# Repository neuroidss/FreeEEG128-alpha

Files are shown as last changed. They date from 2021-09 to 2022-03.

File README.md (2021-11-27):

# FreeEEG128-alpha

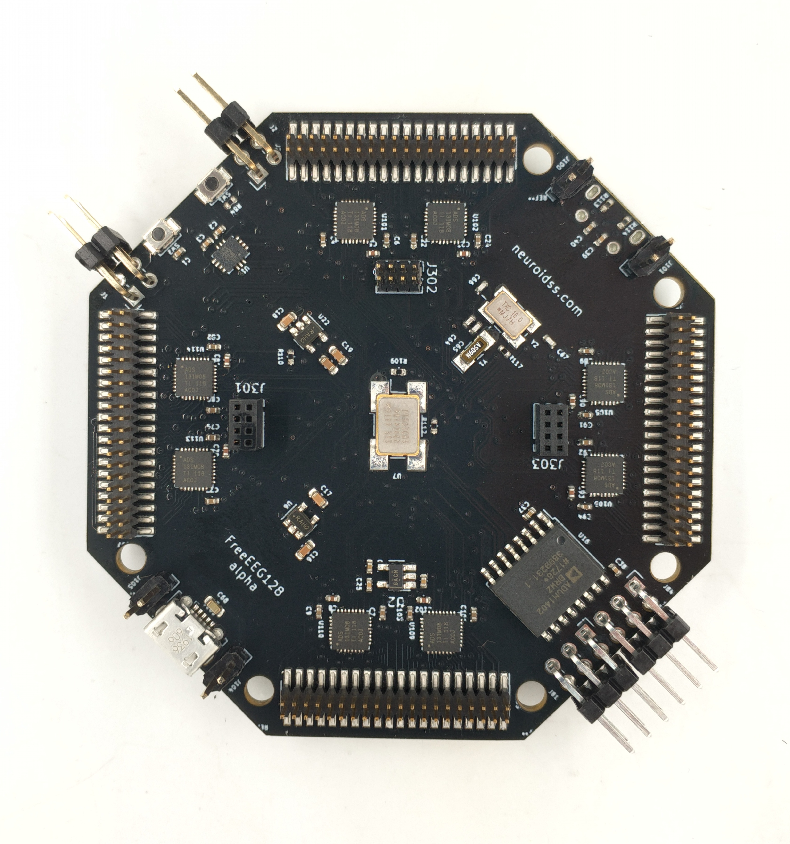
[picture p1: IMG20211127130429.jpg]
FreeEEG128-alpha_top


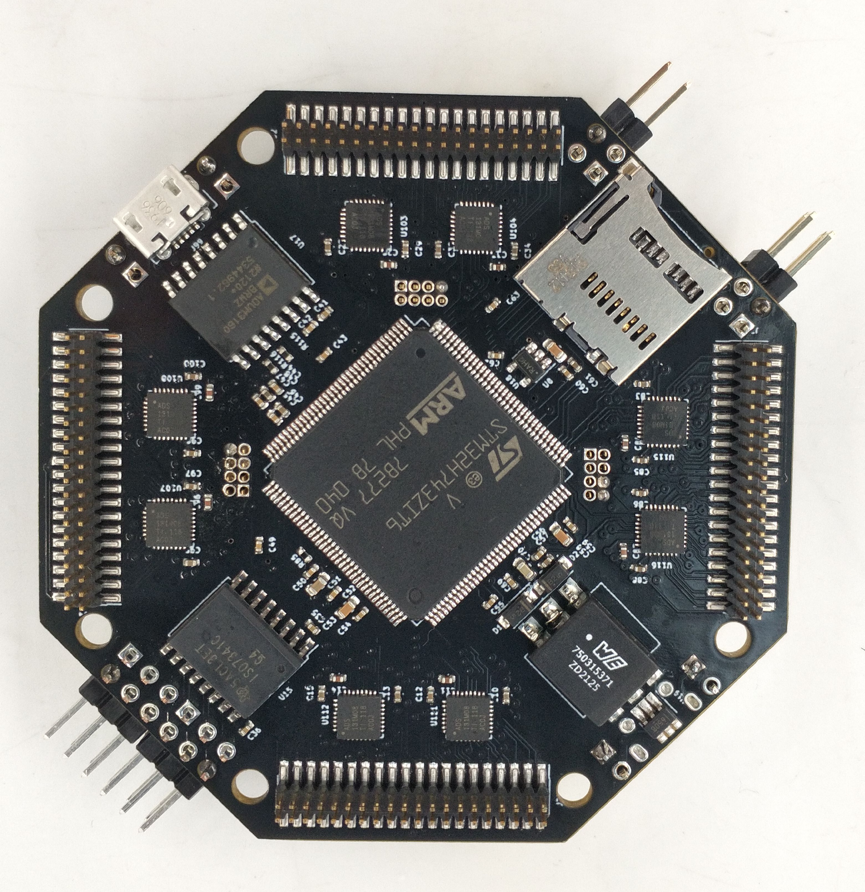
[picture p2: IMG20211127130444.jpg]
FreeEEG128-alpha_bottom


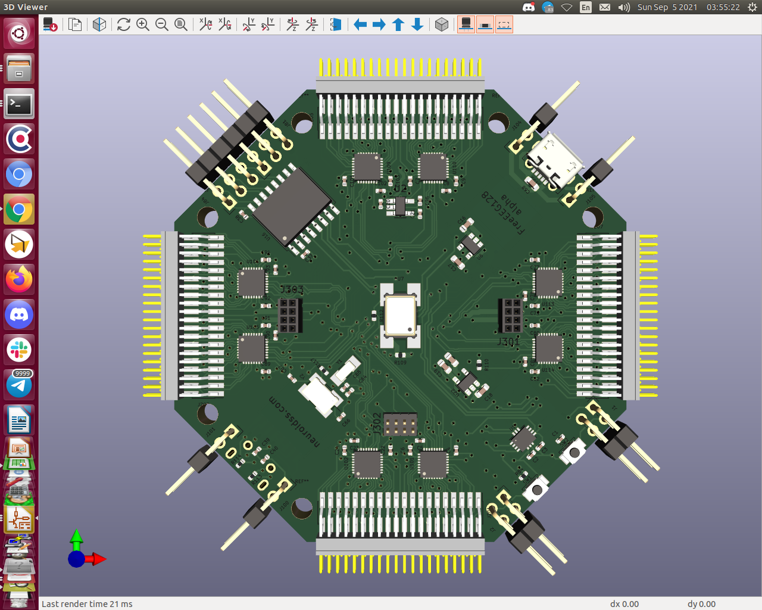
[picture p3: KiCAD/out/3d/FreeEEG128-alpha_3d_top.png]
FreeEEG128-alpha_3d_top


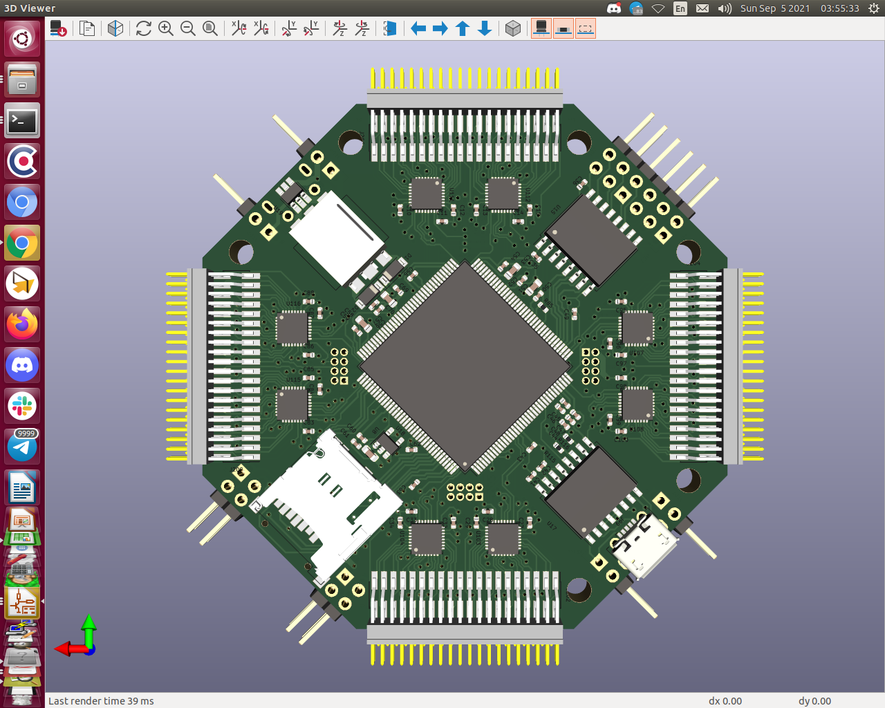
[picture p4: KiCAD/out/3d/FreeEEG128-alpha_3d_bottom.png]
FreeEEG128-alpha_3d_bottom


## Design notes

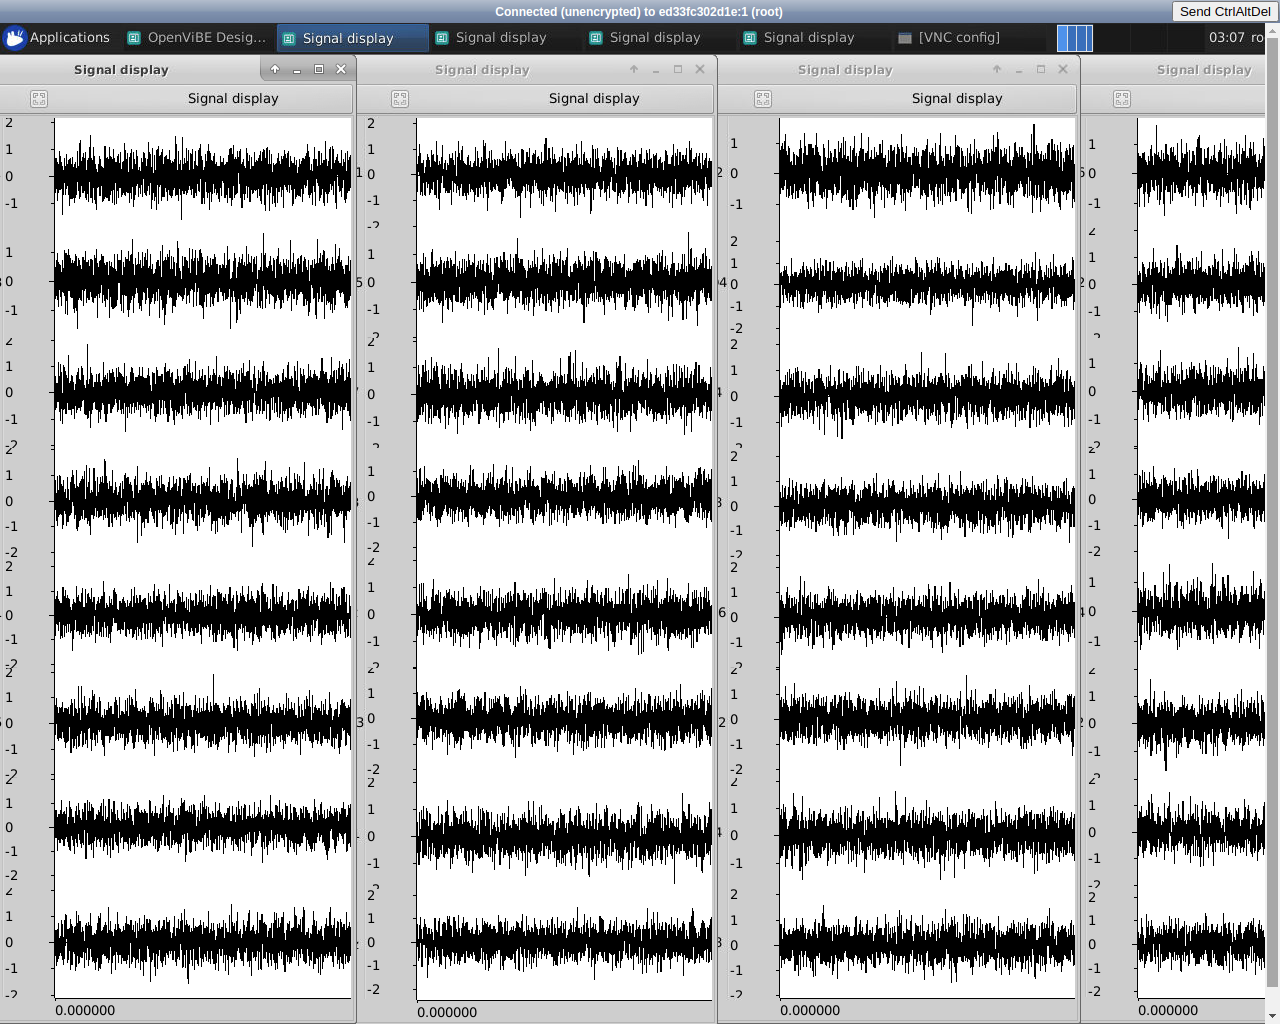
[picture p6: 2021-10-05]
Screenshot from 2021-10-05 06-07-12.png

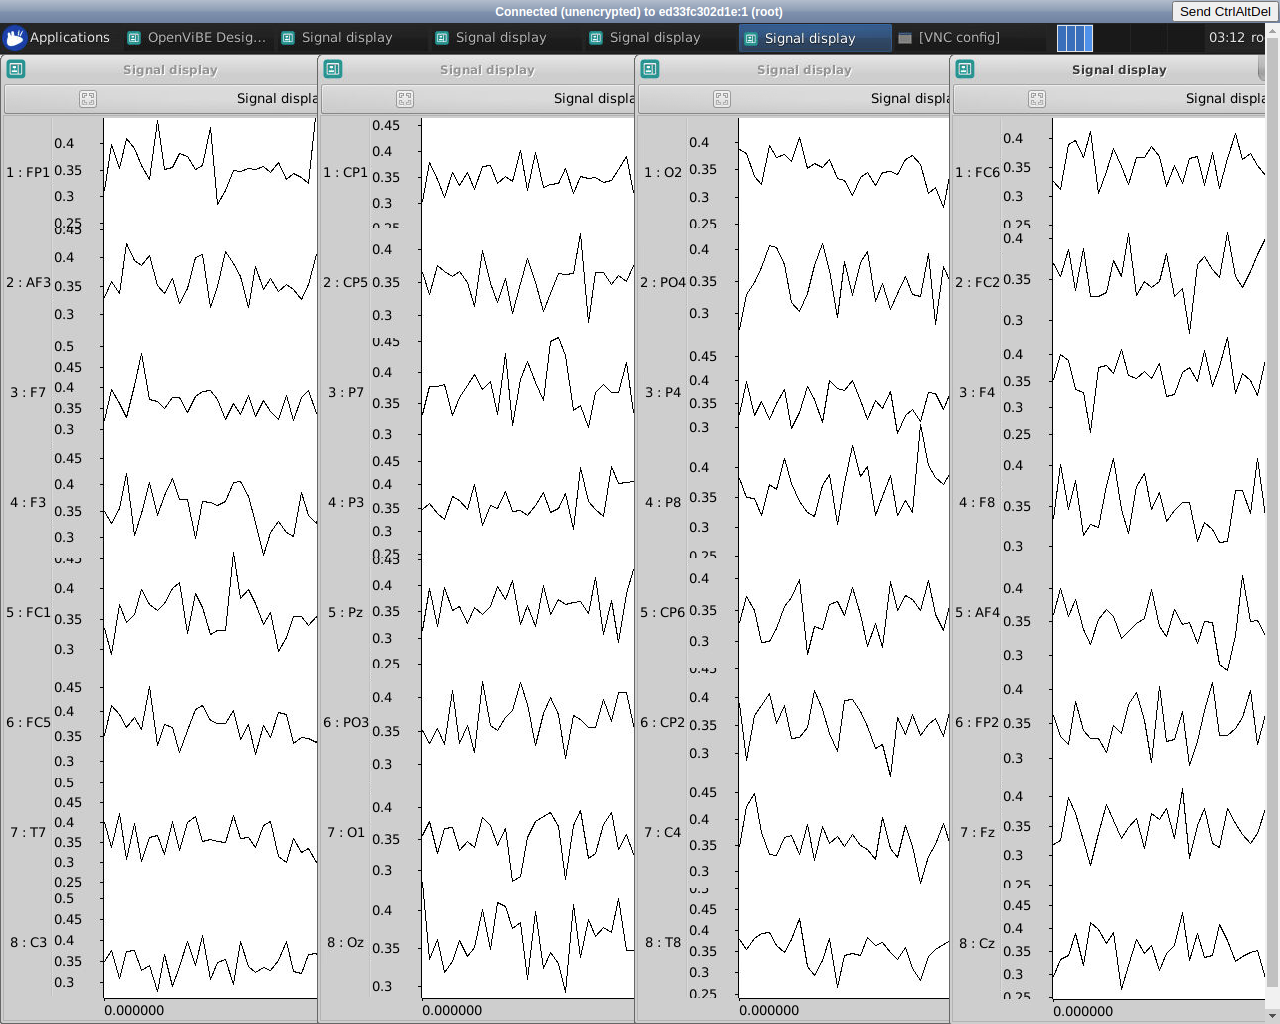
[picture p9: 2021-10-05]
Screenshot from 2021-10-05 06-12-14.png

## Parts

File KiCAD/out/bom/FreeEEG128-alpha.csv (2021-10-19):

Id | Designator | Package | Quantity | Designation | Supplier and ref | Manufacturer Part Number or Seeed SKU | Description | alt
1 | J303,J301 | PinSocket_2x04_P1.27mm_Vertical | 2 | Conn_02x04_Odd_Even |  | 20021311-00008T4LF | CONN RCPT 8POS 0.05 GOLD PCB | 20021311-00008T1LF | LPPB042CFFN-RC
2 | U1 | Bosch_LGA-14_3x2.5mm_P0.5mm | 1 | LSM6DS3 |  | LSM6DSOXTR | IMU ACCEL/GYRO I2C/SPI 14TFLGA | LSM6DS3TR | LSM6DSRXTR | LSM6DSOXTR
3 | C38,C39,C1,C40,C2,C3,C37,C25,C21,C20,C47,C50,C59,C43,C55,C42,C35,C63,C54,C62,C69,C56,C49,C44,C45,C36,C41,C60,C52 | C_0402_1005Metric | 29 | 100n |  | CL05B104KO5NNNC | CAP CER 0.1UF 16V X7R 0402
4 | C66,C64 | C_0402_1005Metric | 2 | CL1 |  | GRM1555C1H200JA01D | CAP CER 20PF 50V C0G/NP0 0402
5 | C16,C17,C19,C18,C76,C53,C58,C75 | C_0603_1608Metric | 8 | 2.2u |  | GRM188R71A225KE15D | CAP CER 2.2UF 10V 10% X7R 0603
6 | R84,R85 | R_0402_1005Metric | 2 | 4k7 |  | RC0402JR-074K7L | RES 4.7K OHM 1/16W 5% 0402 SMD
7 | R113,R114,R116,R115 | R_0402_1005Metric | 4 | 24 |  | RC0402FR-0724RL | RES SMD 24 OHM 1% 1/16W 0402
8 | J104,J105,J100,J101 | PinHeader_2x01_P2.54mm_Horizontal | 4 | Conn_01x02 |  | PRPC001DAAN-RC | CONN HEADER VERT 2POS | PRPC001DAAN-RC | TSW-101-07-F-D
9 | U6,U22,U8 | SOT-23-5 | 3 | LP5907 |  | LP5907QMFX-3.3Q1 | IC REG LINEAR 3.3V 250MA SOT23-5 | ADP7118AUJZ-3.3-R7
10 | Y2 | Crystal_SMD_EuroQuartz_MJ-4Pin_5.0x3.2mm_HandSoldering | 1 | 16MHz |  | 7B-16.000MEEQ-T | CRYSTAL 16.0000MHZ 10PF SMD
11 | C67,C65 | C_0402_1005Metric | 2 | CL2 |  | GRM1555C1H200JA01D | CAP CER 20PF 50V C0G/NP0 0402
12 | C68,C70 | C_0603_1608Metric | 2 | 10u |  | GRM188R60J106ME47D | CAP CER 10UF 6.3V 20% X5R 0603
13 | J103,J99 | USB_Micro-B_Molex-105017-0001 | 2 | USB_B_Micro |  | 105017-1001 | CONN RCPT USB2.0 MICRO B SMD R/A
14 | SW1,SW2 | SW_SPST_B3U-1000P-B | 2 | SW_Push |  | B3U-1000P | Switch Tactile N.O. SPST Round Button Gull Wing 0.05A 12VDC 1.5N SMD Embossed T/R
15 | Y1 | Crystal_SMD_EuroQuartz_EQ161-2Pin_3.2x1.5mm_HandSoldering | 1 | 32768Hz |  | FC-135 32.7680KA-A5 | CRYSTAL 32.7680 KHZ 12.5PF SMD
16 | U7 | Oscillator_SMD_EuroQuartz_XO91-4Pin_7.0x5.0mm_HandSoldering | 1 | FXO-SM7_OSC-SMD7050_short |  | CB3LV-3I-8M1920 | XTAL OSC XO 8.1920MHZ HCMOS TTL
17 | R117 | R_0402_1005Metric | 1 | R_EXT |  | RC0402JR-070RL | RES 0.0 OHM 1/16W JUMP 0402 SMD
18 | J2,J1 | PinHeader_2x02_P2.54mm_Horizontal | 2 | Conn_02x02_Odd_Even |  | 68021-404HLF | CONN HEADER R/A 4POS 2.54MM | PREC002DBAN-M71RC | M20-9950245 | TSW-102-08-T-D-RA | HTSW-102-08-T-D-RA | 68021-404HLF
19 | U16 | SOIC-16W_7.5x10.3mm_P1.27mm | 1 | ADUM1402BRWZ |  | ADUM1402BRWZ | digital isolator 10Mbps 2.7÷5.5VDC SMD SO16-W | ADUM142E1BRWZ
20 | J81,J84 | PinHeader_2x03_P2.54mm_Horizontal | 2 | Conn_02x03_Odd_Even |  | 68021-406HLF | CONN HEADER R/A 6POS 2.54MM | PREC003DBAN-M71RC | PH2RA-06-UA | TSW-103-08-T-D-RA |  | 68021-406HLF
21 | C81,C5,C90,C8,C102,C78,C93,C23,C84,C28,C11,C99,C33,C87,C14,C96 | C_0402_1005Metric | 16 | 220nF |  | CC0402KRX5R5BB224 | CAP CER 0.22UF 16V X7R 0402
22 | C79,C82,C91,C92,C94,C101,C22,C6,C9,C103,C89,C24,C4,C77,C7,C80,C61,C46,C57,C48,C95,C83,C15,C12,C97,C85,C13,C88,C32,C29,C27,C10,C98,C86,C100,C34 | C_0402_1005Metric | 36 | 1u |  | CL05A105KO5NNNC | CAP CER 1UF 16V X5R 0402
23 | U113,U109,U114,U105,U102,U106,U110,U101,U103,U107,U112,U116,U108,U111,U104,U115 | QFN-32-1EP_4x4mm_P0.4mm_EP2.65x2.65mm_ThermalVias | 16 | ADS131M08IRSN |  | ADS131M08IRSN | IC ADC 24BIT SIGMA-DELTA 32WQFN
24 | J207,J203,J201,J205,J208,J204,J202,J206 | PinHeader_2x20_P1.27mm_Vertical_SMD | 8 | Conn_02x20_Odd_Even |  | 20021121-00040T4LF | CONN HEADER SMD 40POS 1.27MM | M50-3612042R | FTSH-120-01-F-DV | M50-3602042 | M50-3612042 |  | FTSH-120-01-F-DV-P | FTSH-120-01-F-DH-A | FTSH-120-04-F-DH-A
25 | J302 | PinHeader_2x04_P1.27mm_Vertical | 1 | Conn_02x04_Odd_Even |  | HPH2-A-08-UA | CONN HEADER VERT 8POS 1.27MM | GRPB042VWVN-RC | 20021111-00008T4LF
27 | R112,R110,R109 | R_0402_1005Metric | 3 | 0 |  | RC0402JR-070RL | RES 0.0 OHM 1/16W JUMP 0402 SMD
28 | U2 | SOT-23-5_HandSoldering | 1 | REF2025 |  | REF2025AIDDC | IC VREF SERIES 1.25V 2.5V SOT-23-5
29 | U19 | SOT-23-6_Handsoldering | 1 | SN6505B |  | SN6505BDBVR | IC TRANSFORMER DRIVER 6SOT-23
30 | C51 | C_0603_1608Metric | 1 | 4.7u |  | C0603C475K9PACTU | CAP CER 4.7UF 6.3V 10% X5R 0603
31 | U18 | LQFP-144_20x20mm_P0.5mm | 1 | STM32H743ZITx |  | STM32H743ZIT6U | HIGH-PERFORMANCE AND DSP WITH DP
32 | U17 | SOIC-16W_7.5x10.3mm_P1.27mm | 1 | ADuM3160 |  | ADUM3160BRWZ | Digital Isolator CMOS 2-CH 12Mbps 16-Pin SOIC W Tube
33 | D2,D1 | D_SOD-123 | 2 | D_Schottky |  | MBR0520LT1G | Rectifier, Schottky Power; Plastic Sod-123; 0.5 a @ +90c If; +125; 20v; 1000
34 | U15 | SOIC-16W_7.5x10.3mm_P1.27mm | 1 | ISO7341c |  | ISO7341CDW | DGTL ISO 3KV 4CH GEN PURP 16SOIC
35 | U21 | 473521001 | 1 | 473521001 |  | 47352-1001 | CONN MICRO SD CARD PUSH-PUSH R/A
36 | T1 | 750315371 | 1 | 750315371 |  | 750315371 | XFRMR FWD P-P DC/DC CONV SMD

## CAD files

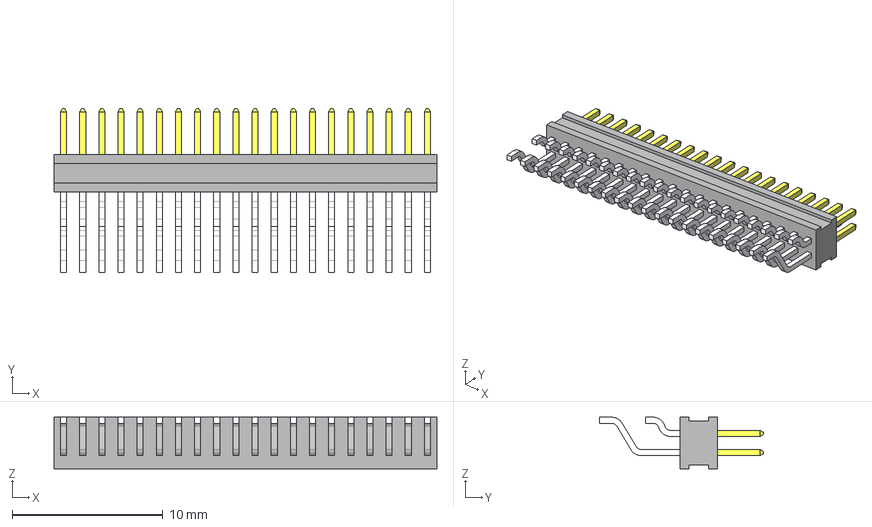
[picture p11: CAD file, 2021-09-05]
KiCAD/3d/Connectors/FTSH-120-01-L-DH-TR.stp
25.4 x 10.9 x 3.43 mm
_FTSH-120-01-L-DH-TR_body
_FTSH-120-01-L-DH-TR_pins1
_FTSH-120-01-L-DH-TR_pins2

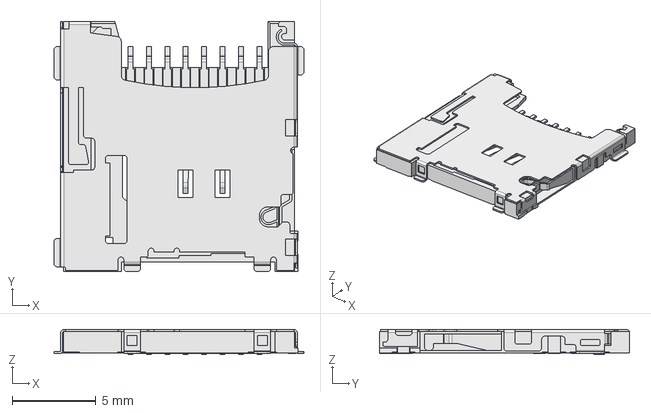
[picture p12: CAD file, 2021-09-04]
KiCAD/3d/Connectors/5031821852.step
14.9 x 14.9 x 1.50 mm

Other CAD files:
KiCAD/3d/Connectors/5031821852.stp

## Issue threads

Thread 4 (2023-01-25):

on freeeeg128-alpha no vref for boards interconnection

dmitry-sukhoruchkin, 2023-01-25:
on freeeeg128-alpha no vref for boards interconnection, vref gnd instead, which duplicated already existed gnd on another connector

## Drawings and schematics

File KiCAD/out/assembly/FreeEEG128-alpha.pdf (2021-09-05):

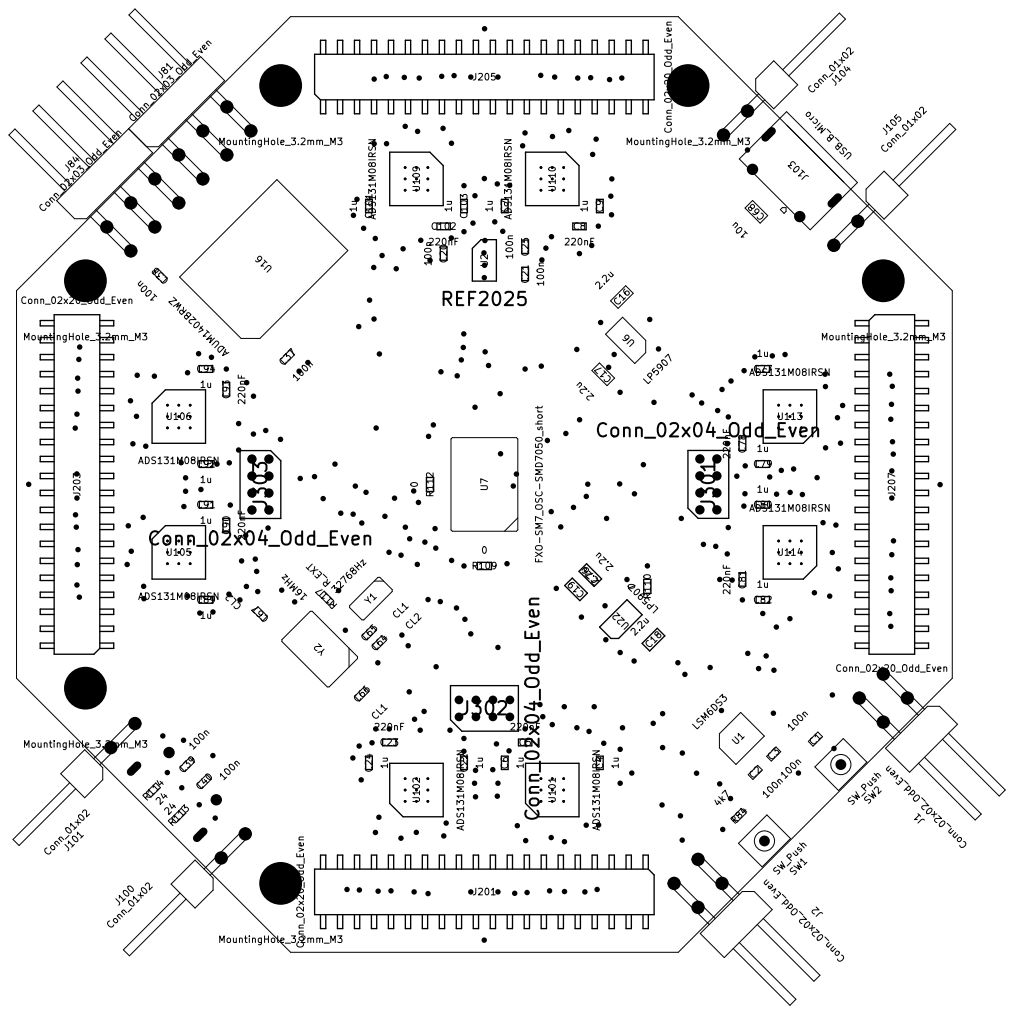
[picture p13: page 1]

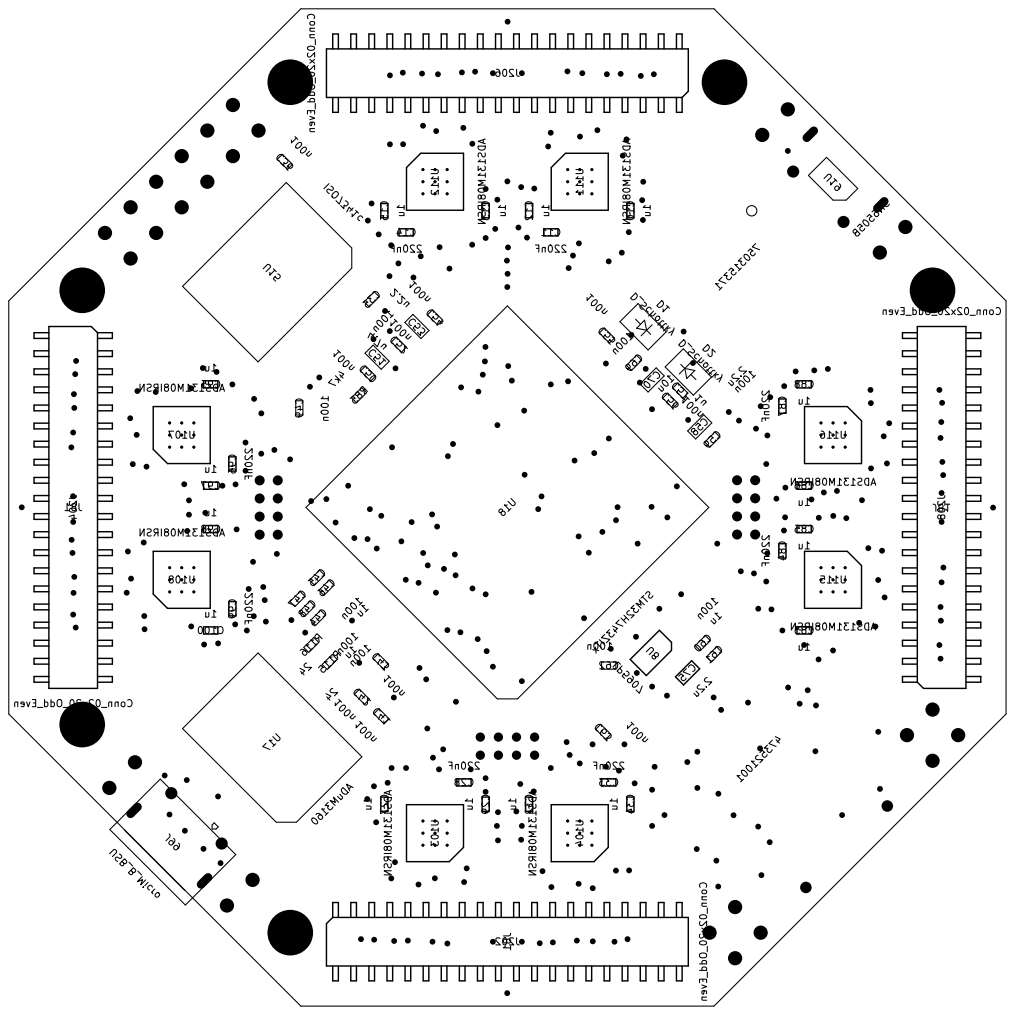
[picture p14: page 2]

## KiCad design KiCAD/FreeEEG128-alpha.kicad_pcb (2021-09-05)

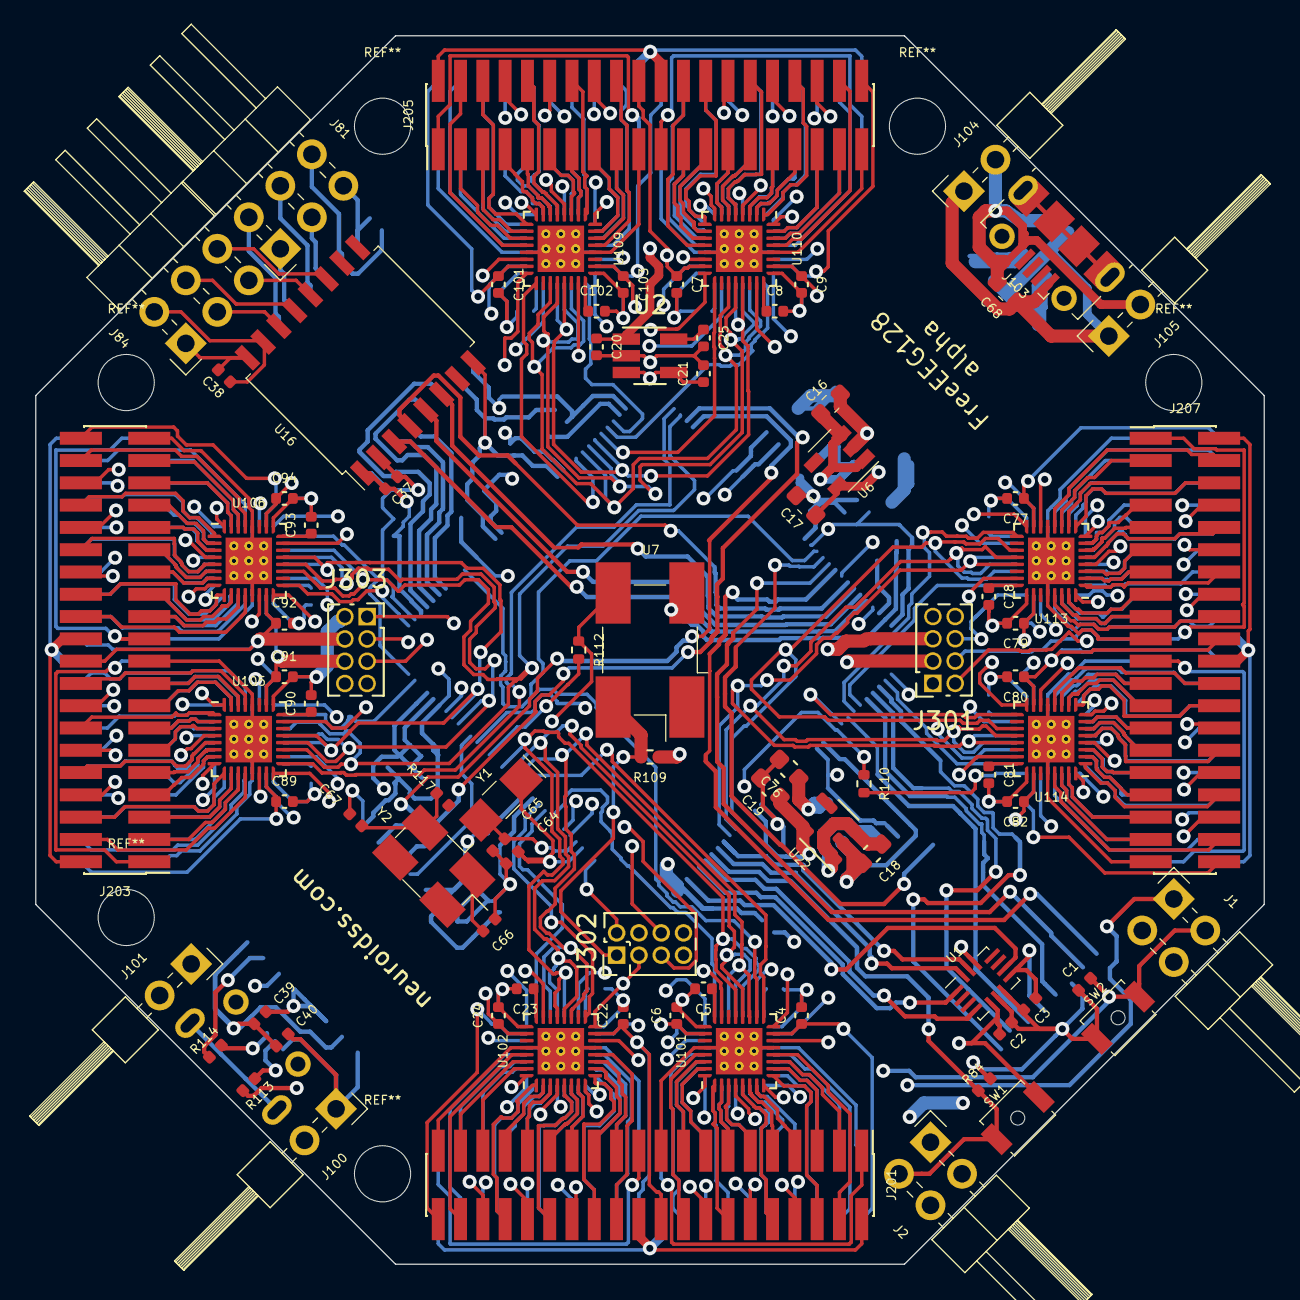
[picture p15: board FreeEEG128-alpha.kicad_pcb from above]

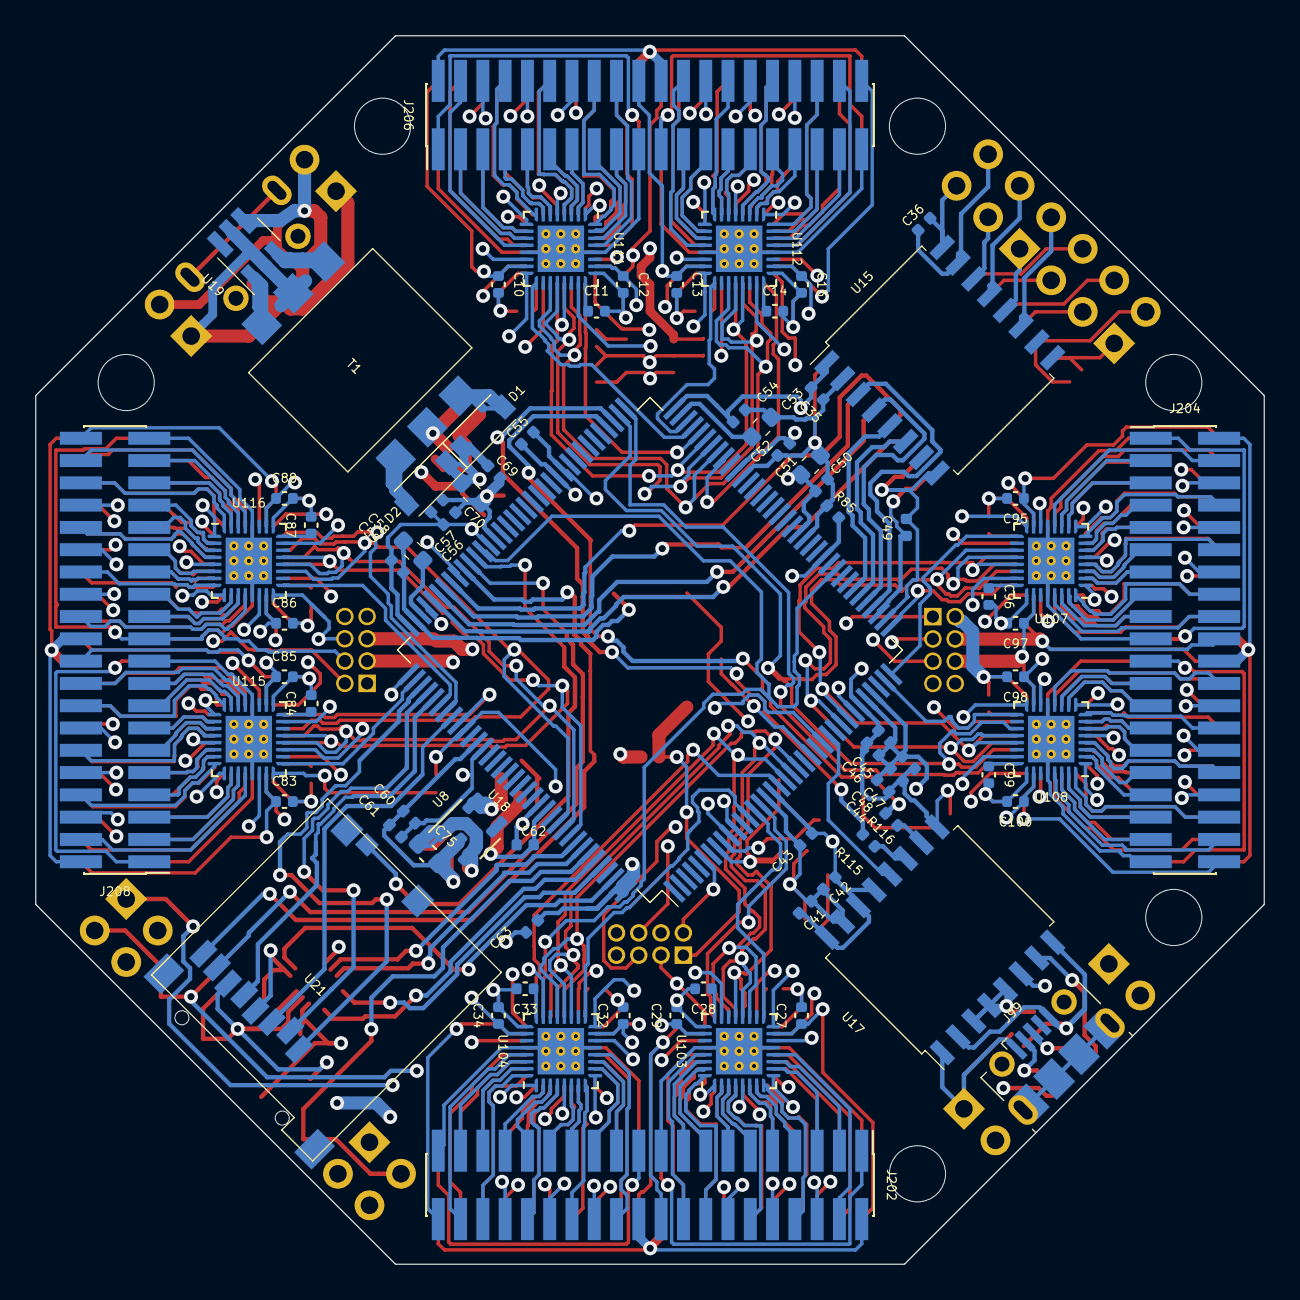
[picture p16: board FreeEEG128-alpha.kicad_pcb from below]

Board: 4 copper layers, 70.0 x 70.0 mm, 162 parts (77 on the bottom side), 379 nets.

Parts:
C1, C2, C3, C20, C21, C25, C35, C36, C37, C38, C39, C40, C41, C42, C43, C44, C45, C47, C49, C50, C52, C54, C55, C56, C59, C60, C62, C63, C69: 100n; C_0402_1005Metric
C4, C6, C7, C9, C10, C12, C13, C15, C22, C24, C27, C29, C32, C34, C46, C48, C57, C61, C77, C79, C80, C82, C83, C85, C86, C88, C89, C91, C92, C94, C95, C97, C98, C100, C101, C103: 1u; C_0402_1005Metric
C5, C8, C11, C14, C23, C28, C33, C78, C81, C84, C87, C90, C93, C96, C99, C102: 220nF; C_0402_1005Metric
C16, C17, C18, C19, C53, C58, C75, C76: 2.2u; C_0603_1608Metric
C51: 4.7u; C_0603_1608Metric
C64, C66: CL1; C_0402_1005Metric
C65, C67: CL2; C_0402_1005Metric
C68, C70: 10u; C_0603_1608Metric
D1, D2: D_Schottky; D_SOD-123
J1, J2: Conn_02x02_Odd_Even; PinHeader_2x02_P2.54mm_Horizontal
J81, J84: Conn_02x03_Odd_Even; PinHeader_2x03_P2.54mm_Horizontal
J99, J103: USB_B_Micro; USB_Micro-B_Molex-105017-0001
J100, J101, J104, J105: Conn_01x02; PinHeader_2x01_P2.54mm_Horizontal
J201, J202, J203, J204, J205, J206, J207, J208: Conn_02x20_Odd_Even; PinHeader_2x20_P1.27mm_Vertical_SMD
J301, J303: Conn_02x04_Odd_Even; PinSocket_2x04_P1.27mm_Vertical
J302: Conn_02x04_Odd_Even; PinHeader_2x04_P1.27mm_Vertical
R84, R85: 4k7; R_0402_1005Metric
R109, R110, R112: 0; R_0402_1005Metric
R113, R114, R115, R116: 24; R_0402_1005Metric
R117: R_EXT; R_0402_1005Metric
SW1, SW2: SW_Push; SW_SPST_B3U-1000P-B
T1: 750315371
U1: LSM6DS3; Bosch_LGA-14_3x2.5mm_P0.5mm
U2: REF2025; SOT-23-5_HandSoldering
U6, U8, U22: LP5907; SOT-23-5
U7: FXO-SM7_OSC-SMD7050_short; Oscillator_SMD_EuroQuartz_XO91-4Pin_7.0x5.0mm_HandSoldering
U15: ISO7341c; SOIC-16W_7.5x10.3mm_P1.27mm
U16: ADUM1402BRWZ; SOIC-16W_7.5x10.3mm_P1.27mm
U17: ADuM3160; SOIC-16W_7.5x10.3mm_P1.27mm
U18: STM32H743ZITx; LQFP-144_20x20mm_P0.5mm
U19: SN6505B; SOT-23-6_Handsoldering
U21: 473521001
U101, U102, U103, U104, U105, U106, U107, U108, U109, U110, U111, U112, U113, U114, U115, U116: ADS131M08IRSN; QFN-32-1EP_4x4mm_P0.4mm_EP2.65x2.65mm_ThermalVias
Y1: 32768Hz; Crystal_SMD_EuroQuartz_EQ161-2Pin_3.2x1.5mm_HandSoldering
Y2: 16MHz; Crystal_SMD_EuroQuartz_MJ-4Pin_5.0x3.2mm_HandSoldering

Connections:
/ADC1/24_CAP: C5.1, U101.24 (CAP)
/ADC2/24_CAP: C23.1, U102.24 (CAP)
/ADC3/24_CAP: C28.1, U103.24 (CAP)
/ADC4/24_CAP: C33.1, U104.24 (CAP)
/ADC5/24_CAP: C90.1, U105.24 (CAP)
/ADC6/24_CAP: C93.1, U106.24 (CAP)
/ADC7/24_CAP: C96.1, U107.24 (CAP)
/ADC8/24_CAP: C99.1, U108.24 (CAP)
/ADC9/24_CAP: C102.1, U109.24 (CAP)
/ADC10/24_CAP: C8.1, U110.24 (CAP)
/ADC11/24_CAP: C11.1, U111.24 (CAP)
/ADC12/24_CAP: C14.1, U112.24 (CAP)
/ADC13/24_CAP: C78.1, U113.24 (CAP)
/ADC14/24_CAP: C81.1, U114.24 (CAP)
/ADC15/24_CAP: C84.1, U115.24 (CAP)
/ADC16/24_CAP: C87.1, U116.24 (CAP)
/MCU/8_PC14: C64.1, U18.8 (PC14), Y1.1
/MCU/9_PC15: C65.1, U18.9 (PC15), Y1.2
/MCU/71_VCAP_1: C53.1, U18.71 (VCAP1)
/MCU/106_VCAP_2: C58.1, U18.106 (VCAP2)
ACC_1_SDO_SAO: U1.1 (SDO/SA0), U18.140 (PB9)
ACC_4_INT1: U1.4 (INT1), U18.139 (PB8)
ACC_6_GND: C1.1, C2.2, C3.2, C4.2, C5.2, C6.2, C7.2, C8.2, C9.2, C10.2, C11.2, C12.2, C13.2, C14.2, C15.2, C16.2, C17.2, C18.2, C19.2, C20.2, C21.2, C22.2, C23.2, C24.2, C25.2, C27.2, C28.2, C29.2, C32.2, C33.2, C34.2, C35.2, C37.2, C41.2, C42.2, C43.2, C44.2, C45.2, C46.2, C47.2, C48.2, C49.2, C50.2, C51.2, C52.2, C53.2, C54.2, C55.2, C56.2, C57.2, C58.2, C59.2, C60.2, C61.2, C62.2, C63.2, C64.2, C65.2, C66.2, C67.2, C69.2, C70.2, C75.2, C76.2, C77.2, C78.2, C79.2, C80.2, C81.2, C82.2, C83.2, C84.2, C85.2, C86.2, C87.2, C88.2, C89.2, C90.2, C91.2, C92.2, C93.2, C94.2, C95.2, C96.2, C97.2, C98.2, C99.2, C100.2, C101.2, C102.2, C103.2, J2.2, J201.19, J201.39, J202.19, J202.39, J203.19, J203.39, J204.19, J204.39, J205.19, J205.39, J206.19, J206.39, J207.19, J207.39, J208.19, J208.39, J301.1, J303.2, R84.2, R85.2, SW2.1, T1.5, U1.6 (GND), U1.7 (GND), U2.2 (GND), U6.2 (GND), U7.2 (GND), U8.2 (GND), U15.2 (GND1), U15.8 (GND1), U16.2 (GND1), U16.8 (GND1), U17.9 (GND2), U17.15 (GND2), U18.16 (VSS), U18.31 (VSSA), U18.38 (VSS), U18.51 (VSS), U18.61 (VSS), U18.83 (VSS), U18.94 (VSS), U18.107 (VSS), U18.120 (VSS), U18.130 (VSS), U21.6 (Vss), U22.2 (GND), U101.13 (AGND), U101.25 (DGND), U101.28 (AGND), U101.33 (Thermal_pad), U102.13 (AGND), U102.25 (DGND), U102.28 (AGND), U102.33 (Thermal_pad), U103.13 (AGND), U103.25 (DGND), U103.28 (AGND), U103.33 (Thermal_pad), U104.13 (AGND), U104.25 (DGND), U104.28 (AGND), U104.33 (Thermal_pad), U105.13 (AGND), U105.25 (DGND), U105.28 (AGND), U105.33 (Thermal_pad), U106.13 (AGND), U106.25 (DGND), U106.28 (AGND), U106.33 (Thermal_pad), U107.13 (AGND), U107.25 (DGND), U107.28 (AGND), U107.33 (Thermal_pad), U108.13 (AGND), U108.25 (DGND), U108.28 (AGND), U108.33 (Thermal_pad), U109.13 (AGND), U109.25 (DGND), U109.28 (AGND), U109.33 (Thermal_pad), U110.13 (AGND), U110.25 (DGND), U110.28 (AGND), U110.33 (Thermal_pad), U111.13 (AGND), U111.25 (DGND), U111.28 (AGND), U111.33 (Thermal_pad), U112.13 (AGND), U112.25 (DGND), U112.28 (AGND), U112.33 (Thermal_pad), U113.13 (AGND), U113.25 (DGND), U113.28 (AGND), U113.33 (Thermal_pad), U114.13 (AGND), U114.25 (DGND), U114.28 (AGND), U114.33 (Thermal_pad), U115.13 (AGND), U115.25 (DGND), U115.28 (AGND), U115.33 (Thermal_pad), U116.13 (AGND), U116.25 (DGND), U116.28 (AGND), U116.33 (Thermal_pad)
ACC_9_INT2: U1.9 (INT2), U18.142 (PE1)
ACC_12_CS: C2.1, C3.1, C19.1, C35.1, C37.1, C41.1, C42.1, C43.1, C44.1, C45.1, C46.1, C47.1, C48.1, C49.1, C50.1, C51.1, C52.1, C54.1, C55.1, C56.1, C57.1, C59.1, C60.1, C61.1, C62.1, C63.1, J2.1, J301.5, J302.2, R109.1, SW1.1, U1.5 (VDDIO), U1.8 (VDD), U1.12 (CS), U15.1 (VCC1), U16.1 (VCC1), U17.13 (SPD), U17.14 (VDD2), U17.16 (VBUS2), U18.6 (VBAT), U18.17 (VDD), U18.30 (VDD), U18.32 (VREF+), U18.33 (VDDA), U18.39 (VDD), U18.52 (VDD), U18.62 (VDD), U18.72 (VDD), U18.84 (VDD), U18.95 (VDD33_USB), U18.108 (VDD), U18.121 (VDD), U18.131 (VDD), U18.143 (PDR_ON), U18.144 (VDD), U21.4 (VDD), U22.5 (OUT)
ACC_13_SCL: U1.13 (SCL), U18.136 (PB6)
ACC_14_SDA: U1.14 (SDA), U18.137 (PB7)
ADC1_01_AIN2P: J201.14, U101.1 (AIN2P)
ADC1_02_AIN2N: J201.13, U101.2 (AIN2N)
ADC1_03_AIN3N: J201.11, U101.3 (AIN3N)
ADC1_04_AIN3P: J201.12, U101.4 (AIN3P)
ADC1_05_AIN4P: J201.10, U101.5 (AIN4P)
ADC1_06_AIN4N: J201.9, U101.6 (AIN4N)
ADC1_07_AIN5N: J201.7, U101.7 (AIN5N)
ADC1_08_AIN5P: J201.8, U101.8 (AIN5P)
ADC1_09_AIN6P: J201.6, U101.9 (AIN6P)
ADC1_10_AIN6N: J201.5, U101.10 (AIN6N)
ADC1_11_AIN7N: J201.3, U101.11 (AIN7N)
ADC1_12_AIN7P: J201.4, U101.12 (AIN7P)
ADC1_17_CS: U18.18 (PF6), U101.17 (CS)
ADC1_18_DRDY: U18.46 (PB0), U18.96 (PC6), U101.18 (DRDY)
ADC1_19_SCLK: U18.19 (PF7), U101.19 (SCLK), U102.19 (SCLK), U103.19 (SCLK), U104.19 (SCLK)
ADC1_20_DOUT: U18.20 (PF8), U101.20 (DOUT), U102.20 (DOUT), U103.20 (DOUT), U104.20 (DOUT)
ADC1_21_DIN: U18.21 (PF9), U101.21 (DIN), U102.21 (DIN), U103.21 (DIN), U104.21 (DIN)
ADC1_29_AIN0P: J201.18, U101.29 (AIN0P)
ADC1_30_AIN0N: J201.17, U101.30 (AIN0N)
ADC1_31_AIN1N: J201.15, U101.31 (AIN1N)
ADC1_32_AIN1P: J201.16, U101.32 (AIN1P)
ADC2_01_AIN2P: J201.34, U102.1 (AIN2P)
ADC2_02_AIN2N: J201.33, U102.2 (AIN2N)
ADC2_03_AIN3N: J201.31, U102.3 (AIN3N)
ADC2_04_AIN3P: J201.32, U102.4 (AIN3P)
ADC2_05_AIN4P: J201.30, U102.5 (AIN4P)
ADC2_06_AIN4N: J201.29, U102.6 (AIN4N)
ADC2_07_AIN5N: J201.27, U102.7 (AIN5N)
ADC2_08_AIN5P: J201.28, U102.8 (AIN5P)
ADC2_09_AIN6P: J201.26, U102.9 (AIN6P)
ADC2_10_AIN6N: J201.25, U102.10 (AIN6N)
ADC2_11_AIN7N: J201.23, U102.11 (AIN7N)
ADC2_12_AIN7P: J201.24, U102.12 (AIN7P)
ADC2_17_CS: U18.15 (PF5), U102.17 (CS)
ADC2_29_AIN0P: J201.38, U102.29 (AIN0P)
ADC2_30_AIN0N: J201.37, U102.30 (AIN0N)
ADC2_31_AIN1N: J201.35, U102.31 (AIN1N)
ADC2_32_AIN1P: J201.36, U102.32 (AIN1P)
ADC3_01_AIN2P: J202.14, U103.1 (AIN2P)
ADC3_02_AIN2N: J202.13, U103.2 (AIN2N)
ADC3_03_AIN3N: J202.11, U103.3 (AIN3N)
ADC3_04_AIN3P: J202.12, U103.4 (AIN3P)
ADC3_05_AIN4P: J202.10, U103.5 (AIN4P)
ADC3_06_AIN4N: J202.9, U103.6 (AIN4N)
ADC3_07_AIN5N: J202.7, U103.7 (AIN5N)
ADC3_08_AIN5P: J202.8, U103.8 (AIN5P)
ADC3_09_AIN6P: J202.6, U103.9 (AIN6P)
ADC3_10_AIN6N: J202.5, U103.10 (AIN6N)
ADC3_11_AIN7N: J202.3, U103.11 (AIN7N)
ADC3_12_AIN7P: J202.4, U103.12 (AIN7P)
ADC3_17_CS: U18.14 (PF4), U103.17 (CS)
ADC3_29_AIN0P: J202.18, U103.29 (AIN0P)
ADC3_30_AIN0N: J202.17, U103.30 (AIN0N)
ADC3_31_AIN1N: J202.15, U103.31 (AIN1N)
ADC3_32_AIN1P: J202.16, U103.32 (AIN1P)
ADC4_01_AIN2P: J202.34, U104.1 (AIN2P)
ADC4_02_AIN2N: J202.33, U104.2 (AIN2N)
ADC4_03_AIN3N: J202.31, U104.3 (AIN3N)
ADC4_04_AIN3P: J202.32, U104.4 (AIN3P)
ADC4_05_AIN4P: J202.30, U104.5 (AIN4P)
ADC4_06_AIN4N: J202.29, U104.6 (AIN4N)
ADC4_07_AIN5N: J202.27, U104.7 (AIN5N)
ADC4_08_AIN5P: J202.28, U104.8 (AIN5P)
ADC4_09_AIN6P: J202.26, U104.9 (AIN6P)
ADC4_10_AIN6N: J202.25, U104.10 (AIN6N)
ADC4_11_AIN7N: J202.23, U104.11 (AIN7N)
ADC4_12_AIN7P: J202.24, U104.12 (AIN7P)
ADC4_17_CS: U18.13 (PF3), U104.17 (CS)
ADC4_29_AIN0P: J202.38, U104.29 (AIN0P)
ADC4_30_AIN0N: J202.37, U104.30 (AIN0N)
ADC4_31_AIN1N: J202.35, U104.31 (AIN1N)
ADC4_32_AIN1P: J202.36, U104.32 (AIN1P)
ADC5_01_AIN2P: J203.14, U105.1 (AIN2P)
ADC5_02_AIN2N: J203.13, U105.2 (AIN2N)
ADC5_03_AIN3N: J203.11, U105.3 (AIN3N)
ADC5_04_AIN3P: J203.12, U105.4 (AIN3P)
ADC5_05_AIN4P: J203.10, U105.5 (AIN4P)
ADC5_06_AIN4N: J203.9, U105.6 (AIN4N)
ADC5_07_AIN5N: J203.7, U105.7 (AIN5N)
ADC5_08_AIN5P: J203.8, U105.8 (AIN5P)
ADC5_09_AIN6P: J203.6, U105.9 (AIN6P)
ADC5_10_AIN6N: J203.5, U105.10 (AIN6N)
ADC5_11_AIN7N: J203.3, U105.11 (AIN7N)
ADC5_12_AIN7P: J203.4, U105.12 (AIN7P)
ADC5_17_CS: U18.73 (PB12), U105.17 (CS)
ADC5_19_SCLK: U18.74 (PB13), U105.19 (SCLK), U106.19 (SCLK), U107.19 (SCLK), U108.19 (SCLK)
ADC5_20_DOUT: U18.28 (PC2_C), U105.20 (DOUT), U106.20 (DOUT), U107.20 (DOUT), U108.20 (DOUT)
ADC5_21_DIN: U18.29 (PC3_C), U105.21 (DIN), U106.21 (DIN), U107.21 (DIN), U108.21 (DIN)
ADC5_29_AIN0P: J203.18, U105.29 (AIN0P)
ADC5_30_AIN0N: J203.17, U105.30 (AIN0N)
ADC5_31_AIN1N: J203.15, U105.31 (AIN1N)
ADC5_32_AIN1P: J203.16, U105.32 (AIN1P)
ADC6_01_AIN2P: J203.34, U106.1 (AIN2P)
ADC6_02_AIN2N: J203.33, U106.2 (AIN2N)
ADC6_03_AIN3N: J203.31, U106.3 (AIN3N)
ADC6_04_AIN3P: J203.32, U106.4 (AIN3P)
ADC6_05_AIN4P: J203.30, U106.5 (AIN4P)
ADC6_06_AIN4N: J203.29, U106.6 (AIN4N)
ADC6_07_AIN5N: J203.27, U106.7 (AIN5N)
ADC6_08_AIN5P: J203.28, U106.8 (AIN5P)
ADC6_09_AIN6P: J203.26, U106.9 (AIN6P)
ADC6_10_AIN6N: J203.25, U106.10 (AIN6N)
ADC6_11_AIN7N: J203.23, U106.11 (AIN7N)
ADC6_12_AIN7P: J203.24, U106.12 (AIN7P)
ADC6_17_CS: U18.37 (PA3), U106.17 (CS)
ADC6_29_AIN0P: J203.38, U106.29 (AIN0P)
ADC6_30_AIN0N: J203.37, U106.30 (AIN0N)
ADC6_31_AIN1N: J203.35, U106.31 (AIN1N)
ADC6_32_AIN1P: J203.36, U106.32 (AIN1P)
ADC7_01_AIN2P: J204.14, U107.1 (AIN2P)
ADC7_02_AIN2N: J204.13, U107.2 (AIN2N)
ADC7_03_AIN3N: J204.11, U107.3 (AIN3N)
ADC7_04_AIN3P: J204.12, U107.4 (AIN3P)
ADC7_05_AIN4P: J204.10, U107.5 (AIN4P)
ADC7_06_AIN4N: J204.9, U107.6 (AIN4N)
ADC7_07_AIN5N: J204.7, U107.7 (AIN5N)
ADC7_08_AIN5P: J204.8, U107.8 (AIN5P)
ADC7_09_AIN6P: J204.6, U107.9 (AIN6P)
ADC7_10_AIN6N: J204.5, U107.10 (AIN6N)
ADC7_11_AIN7N: J204.3, U107.11 (AIN7N)
ADC7_12_AIN7P: J204.4, U107.12 (AIN7P)
ADC7_17_CS: U18.36 (PA2), U107.17 (CS)
ADC7_29_AIN0P: J204.18, U107.29 (AIN0P)
ADC7_30_AIN0N: J204.17, U107.30 (AIN0N)
ADC7_31_AIN1N: J204.15, U107.31 (AIN1N)
ADC7_32_AIN1P: J204.16, U107.32 (AIN1P)
ADC8_01_AIN2P: J204.34, U108.1 (AIN2P)
ADC8_02_AIN2N: J204.33, U108.2 (AIN2N)
ADC8_03_AIN3N: J204.31, U108.3 (AIN3N)
ADC8_04_AIN3P: J204.32, U108.4 (AIN3P)
ADC8_05_AIN4P: J204.30, U108.5 (AIN4P)
ADC8_06_AIN4N: J204.29, U108.6 (AIN4N)
ADC8_07_AIN5N: J204.27, U108.7 (AIN5N)
ADC8_08_AIN5P: J204.28, U108.8 (AIN5P)
ADC8_09_AIN6P: J204.26, U108.9 (AIN6P)
ADC8_10_AIN6N: J204.25, U108.10 (AIN6N)
ADC8_11_AIN7N: J204.23, U108.11 (AIN7N)
ADC8_12_AIN7P: J204.24, U108.12 (AIN7P)
ADC8_17_CS: U18.35 (PA1), U108.17 (CS)
ADC8_29_AIN0P: J204.38, U108.29 (AIN0P)
ADC8_30_AIN0N: J204.37, U108.30 (AIN0N)
ADC8_31_AIN1N: J204.35, U108.31 (AIN1N)
ADC8_32_AIN1P: J204.36, U108.32 (AIN1P)
ADC9_01_AIN2P: J205.14, U109.1 (AIN2P)
ADC9_02_AIN2N: J205.13, U109.2 (AIN2N)
ADC9_03_AIN3N: J205.11, U109.3 (AIN3N)
ADC9_04_AIN3P: J205.12, U109.4 (AIN3P)
ADC9_05_AIN4P: J205.10, U109.5 (AIN4P)
ADC9_06_AIN4N: J205.9, U109.6 (AIN4N)
ADC9_07_AIN5N: J205.7, U109.7 (AIN5N)
ADC9_08_AIN5P: J205.8, U109.8 (AIN5P)
ADC9_09_AIN6P: J205.6, U109.9 (AIN6P)
ADC9_10_AIN6N: J205.5, U109.10 (AIN6N)
ADC9_11_AIN7N: J205.3, U109.11 (AIN7N)
ADC9_12_AIN7P: J205.4, U109.12 (AIN7P)
ADC9_17_CS: U18.64 (PE11), U109.17 (CS)
ADC9_29_AIN0P: J205.18, U109.29 (AIN0P)
ADC9_30_AIN0N: J205.17, U109.30 (AIN0N)
ADC9_31_AIN1N: J205.15, U109.31 (AIN1N)
ADC9_32_AIN1P: J205.16, U109.32 (AIN1P)
ADC10_01_AIN2P: J205.34, U110.1 (AIN2P)
ADC10_02_AIN2N: J205.33, U110.2 (AIN2N)
ADC10_03_AIN3N: J205.31, U110.3 (AIN3N)
ADC10_04_AIN3P: J205.32, U110.4 (AIN3P)
ADC10_05_AIN4P: J205.30, U110.5 (AIN4P)
ADC10_06_AIN4N: J205.29, U110.6 (AIN4N)
ADC10_07_AIN5N: J205.27, U110.7 (AIN5N)
ADC10_08_AIN5P: J205.28, U110.8 (AIN5P)
ADC10_09_AIN6P: J205.26, U110.9 (AIN6P)
ADC10_10_AIN6N: J205.25, U110.10 (AIN6N)
ADC10_11_AIN7N: J205.23, U110.11 (AIN7N)
ADC10_12_AIN7P: J205.24, U110.12 (AIN7P)
ADC10_14_REFIN: C20.1, U2.1 (VBIAS), U101.14 (REFIN), U102.14 (REFIN), U103.14 (REFIN), U104.14 (REFIN), U105.14 (REFIN), U106.14 (REFIN), U107.14 (REFIN), U108.14 (REFIN), U109.14 (REFIN), U110.14 (REFIN), U111.14 (REFIN), U112.14 (REFIN), U113.14 (REFIN), U114.14 (REFIN), U115.14 (REFIN), U116.14 (REFIN)
ADC10_15_AVDD: C4.1, C7.1, C10.1, C13.1, C17.1, C22.1, C27.1, C32.1, C77.1, C80.1, C83.1, C86.1, C89.1, C92.1, C95.1, C98.1, C101.1, J201.20, J201.40, J202.20, J202.40, J203.20, J203.40, J204.20, J204.40, J205.20, J205.40, J206.20, J206.40, J207.20, J207.40, J208.20, J208.40, J303.4, U6.5 (OUT), U101.15 (AVDD), U102.15 (AVDD), U103.15 (AVDD), U104.15 (AVDD), U105.15 (AVDD), U106.15 (AVDD), U107.15 (AVDD), U108.15 (AVDD), U109.15 (AVDD), U110.15 (AVDD), U111.15 (AVDD), U112.15 (AVDD), U113.15 (AVDD), U114.15 (AVDD), U115.15 (AVDD), U116.15 (AVDD)
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

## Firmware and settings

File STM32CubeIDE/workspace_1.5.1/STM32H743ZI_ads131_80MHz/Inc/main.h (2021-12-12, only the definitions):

#define ADC2_DRDY_Pin GPIO_PIN_13
#define ADC2_DRDY_GPIO_Port GPIOC
#define SPI5_NSS4_Pin GPIO_PIN_3
#define SPI5_NSS4_GPIO_Port GPIOF
#define SPI5_NSS3_Pin GPIO_PIN_4
#define SPI5_NSS3_GPIO_Port GPIOF
#define SPI5_NSS2_Pin GPIO_PIN_5
#define SPI5_NSS2_GPIO_Port GPIOF
#define SPI5_NSS_Pin GPIO_PIN_6
#define SPI5_NSS_GPIO_Port GPIOF
#define ADC3_DRDY_Pin GPIO_PIN_10
#define ADC3_DRDY_GPIO_Port GPIOF
#define ISO_USB_PIN_Pin GPIO_PIN_0
#define ISO_USB_PIN_GPIO_Port GPIOC
#define SPI2_NSS2_Pin GPIO_PIN_1
#define SPI2_NSS2_GPIO_Port GPIOA
#define SPI2_NSS3_Pin GPIO_PIN_2
#define SPI2_NSS3_GPIO_Port GPIOA
#define SPI2_NSS4_Pin GPIO_PIN_3
#define SPI2_NSS4_GPIO_Port GPIOA
#define SPI1_NSS_Pin GPIO_PIN_4
#define SPI1_NSS_GPIO_Port GPIOA
#define ADC1_DRDY_Pin GPIO_PIN_0
#define ADC1_DRDY_GPIO_Port GPIOB
#define ADC1_DRDY_EXTI_IRQn EXTI0_IRQn
#define BOOT1_Pin GPIO_PIN_2
#define BOOT1_GPIO_Port GPIOB
#define SPI4_NSS_Pin GPIO_PIN_11
#define SPI4_NSS_GPIO_Port GPIOE
#define SPI4_NSS2_Pin GPIO_PIN_15
#define SPI4_NSS2_GPIO_Port GPIOE
#define SPI4_NSS3_Pin GPIO_PIN_10
#define SPI4_NSS3_GPIO_Port GPIOB
#define SPI4_NSS4_Pin GPIO_PIN_11
#define SPI4_NSS4_GPIO_Port GPIOB
#define SPI2_NSS_Pin GPIO_PIN_12
#define SPI2_NSS_GPIO_Port GPIOB
#define ADC4_DRDY_Pin GPIO_PIN_4
#define ADC4_DRDY_GPIO_Port GPIOG
#define SPI6_NSS4_Pin GPIO_PIN_5
#define SPI6_NSS4_GPIO_Port GPIOG
#define SPI6_NSS3_Pin GPIO_PIN_6
#define SPI6_NSS3_GPIO_Port GPIOG
#define SPI6_NSS2_Pin GPIO_PIN_7
#define SPI6_NSS2_GPIO_Port GPIOG
#define SPI6_NSS_Pin GPIO_PIN_8
#define SPI6_NSS_GPIO_Port GPIOG
#define SDMMC1_DETECT_Pin GPIO_PIN_7
#define SDMMC1_DETECT_GPIO_Port GPIOC
#define SPI3_NSS_Pin GPIO_PIN_15
#define SPI3_NSS_GPIO_Port GPIOA
#define SPI3_NSS2_Pin GPIO_PIN_0
#define SPI3_NSS2_GPIO_Port GPIOD
#define SPI3_NSS3_Pin GPIO_PIN_1
#define SPI3_NSS3_GPIO_Port GPIOD
#define SPI3_NSS4_Pin GPIO_PIN_3
#define SPI3_NSS4_GPIO_Port GPIOD
#define ADC1_SYNC_RESET_Pin GPIO_PIN_4
#define ADC1_SYNC_RESET_GPIO_Port GPIOD
#define ACC_INT1_Pin GPIO_PIN_8
#define ACC_INT1_GPIO_Port GPIOB
#define ACC_SDO_SAO_Pin GPIO_PIN_9
#define ACC_SDO_SAO_GPIO_Port GPIOB
#define AD_DRDY_Pin ADC1_DRDY_Pin
#define AD_DRDY_GPIO_Port ADC1_DRDY_GPIO_Port
#define DHCP_SOCKET     0
#define DNS_SOCKET      1
#define HTTP_SOCKET     2
#define W5500_CS_GPIO_Port SPI1_NSS_GPIO_Port
#define W5500_CS_Pin SPI1_NSS_Pin
#define FREESMARTEEG_OPENBCI                   (1LL<<0)
#define FREESMARTEEG_PROCESSING                (1LL<<1)
#define FREESMARTEEG_CRC                       (1LL<<2)
#define FREESMARTEEG_TEXT                      (1LL<<3)
#define FREESMARTEEG_SAMPLECOUNT               (1LL<<4)
#define FREESMARTEEG_BLINK                     (1LL<<5)
#define FREESMARTEEG_FFT                       (1LL<<6)
#define FREESMARTEEG_DIF                       (1LL<<7)
#define FREESMARTEEG_TEST_COUNTER              (1LL<<8)
#define FREESMARTEEG_TEXT_UART1                (1LL<<9)
#define FREESMARTEEG_OPENVIBE_TELNET           (1LL<<10)
#define FREESMARTEEG_ARDUINO_MEGA_DISPLAY      (1LL<<11)
#define FREESMARTEEG_OPENVIBE_TELNET_PACKET    (1LL<<12)
#define FREESMARTEEG_OPENBCI_TELNET_PACKET     (1LL<<13)
#define FREESMARTEEG_OPENVIBE_FREEEEG32        (1LL<<14)
#define FREESMARTEEG_CHANNELS_STATE            (1LL<<15)
#define FREESMARTEEG_FFT_DISPLAY               (1LL<<16)
#define FREESMARTEEG_TEST_BLINK                (1LL<<17)
#define FREESMARTEEG_STABLE_CRC                (1LL<<18)
#define FREESMARTEEG_TEST_COUNTER2             (1LL<<19)
#define FREESMARTEEG_TEST_BLINK2               (1LL<<20)
#define FREESMARTEEG_DEVICES_STATE             (1LL<<21)
#define FREESMARTEEG_TEXT_USB                  (1LL<<22)
#define FREESMARTEEG_TEXT_SDCARD               (1LL<<23)
#define FREESMARTEEG_SDCARD_TEXT               (1LL<<24)
#define FREESMARTEEG_TEST_SDCARD               (1LL<<25)
#define FREESMARTEEG_WRITE_SDCARD              (1LL<<26)
#define FREESMARTEEG_SDCARD_OPENVIBE           (1LL<<27)
#define FREESMARTEEG_WRITE_SDCARD_OPENVIBE     (1LL<<28)
#define FREESMARTEEG_SDCARD_FORMAT             (1LL<<29)
#define FREESMARTEEG_TEXT_UART7                (1LL<<30)
#define FREESMARTEEG_DATA_TEXT_UART7           (1LL<<31)
#define FREESMARTEEG_DATA_OPENVIBE_FREEEEG32   (1LL<<32)
#define FREESMARTEEG_TEST_ACCGYR_SPI3          (1LL<<33)
#define FREESMARTEEG_OPENVIBE_FREEEEG32_CUSTOM (1LL<<34)
#define FREESMARTEEG_DATA_OPENVIBE_FREEEEG32_CUSTOM (1LL<<35)
#define FREESMARTEEG_DATA_TEXT_UART7_INT       (1LL<<36)
#define FREESMARTEEG_DATA_OPENVIBE_FREEEEG32_CUSTOM_INT (1LL<<37)
#define FREESMARTEEG_SPI_OPENVIBE_FREEEEG32_CUSTOM_INT (1LL<<38)
#define FREESMARTEEG_TEXT_UART7_SAI2B_TIMER     (1LL<<40)
#define FREESMARTEEG_OPENVIBE_FREEEEG32_UART7_SAI2B_TIMER     (1LL<<41)
#define FREESMARTEEG_DMA_UART7_SAI2B_TIMER     (1LL<<42)
#define FREESMARTEEG_SAI_TEXT_UART7_INT       (1LL<<43)
#define FREESMARTEEG_SAI_OPENVIBE_FREEEEG32_CUSTOM_INT (1LL<<44)
#define FREESMARTEEG_SAI_TEXT_UART7     (1LL<<45)
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

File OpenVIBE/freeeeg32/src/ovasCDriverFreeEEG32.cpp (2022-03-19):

/*
 * FreeEEG32 driver for OpenViBE
 *
 * \author Jeremy Frey
 * \author Yann Renard
 *
 */

#include "ovasCDriverFreeEEG32.h"
#include "ovasCConfigurationFreeEEG32.h"

#include <toolkit/ovtk_all.h>

#include <system/ovCTime.h>
#include <system/ovCMemory.h>
#include <cmath>
#include <iostream>
#include <algorithm>

#include <time.h>
#include <cstring>
#include <sstream>

#if defined TARGET_OS_Windows
 #include <windows.h>
 #include <winbase.h>
 #include <cstdio>
 #include <cstdlib>
 #include <commctrl.h>
 #include <winsock2.h> // htons and co.
 //#define TERM_SPEED 57600
// #define TERM_SPEED CBR_115200 // FreeEEG32 is a bit faster than others
// #define TERM_SPEED 921600 // FreeEEG32 is a bit faster than others
 #define TERM_SPEED 1500000 // FreeEEG32 is a bit faster than others
#elif defined TARGET_OS_Linux
 #include <cstdio>
 #include <unistd.h>
 #include <fcntl.h>
 #include <termios.h>
 #include <sys/select.h>
 #include <netinet/in.h> // htons and co.
 #include <unistd.h>
// #define TERM_SPEED B115200
 #define TERM_SPEED 1500000
// #define TERM_SPEED 921600
#else
#endif

#define boolean OpenViBE::boolean
using namespace OpenViBEAcquisitionServer;
using namespace OpenViBE;
using namespace OpenViBE::Kernel;

// packet number at initialization
#define UNINITIALIZED_PACKET_NUMBER -1
#define UNDEFINED_DEVICE_IDENTIFIER uint32(-1)
#define READ_ERROR uint32(-1)
#define WRITE_ERROR uint32(-1)

// start and stop bytes from FreeEEG32 protocl
#define SAMPLE_START_BYTE 0xA0
#define SAMPLE_STOP_BYTE 0xC0

// some constants related to the sendCommand
//#define AD7770_VREF 4.5  // reference voltage for ADC in AD7770.  set by its hardware
//#define AD7770_VREF 2.5  // reference voltage for ADC in AD7770.  set by its hardware
#define AD7770_VREF 1.25  // reference voltage for ADC in AD7770.  set by its hardware
//#define AD7770_GAIN 24.0  //assumed gain setting for AD7770.  set by its Arduino code
//#define AD7770_GAIN 8.0  //assumed gain setting for AD7770.  set by its Arduino code
#define AD7770_GAIN 32.0  //assumed gain setting for AD7770.  set by its Arduino code

// configuration tokens
#define Token_MissingSampleDelayBeforeReset       "AcquisitionDriver_FreeEEG32_MissingSampleDelayBeforeReset"
#define Token_DroppedSampleCountBeforeReset       "AcquisitionDriver_FreeEEG32_DroppedSampleCountBeforeReset"
#define Token_DroppedSampleSafetyDelayBeforeReset "AcquisitionDriver_FreeEEG32_DroppedSampleSafetyDelayBeforeReset"

//___________________________________________________________________//
// Heavily inspired by OpenEEG code. Will override channel count and sampling late upon "daisy" selection. If daisy module is attached, will concatenate EEG values and average accelerometer values every two samples.
//                                                                   //

CDriverFreeEEG32::CDriverFreeEEG32(IDriverContext& rDriverContext)
	:IDriver(rDriverContext)
	,m_oSettings("AcquisitionServer_Driver_FreeEEG32", m_rDriverContext.getConfigurationManager())
	,m_pCallback(NULL)
	,m_ui32ChannelCount(EEGValueBufferSize+AccValueBufferSize)
	,m_ui32DeviceIdentifier(UNDEFINED_DEVICE_IDENTIFIER)
	,m_bDaisyModule(false)
{
	m_sAdditionalCommands="";
	m_ui32ReadBoardReplyTimeout=5000;
	m_ui32FlushBoardReplyTimeout=500;
	m_sDriverName = "FreeEEG32";

	m_oSettings.add("Header", &m_oHeader);
	m_oSettings.add("DeviceIdentifier", &m_ui32DeviceIdentifier);
	m_oSettings.add("ComInit", &m_sAdditionalCommands);
	m_oSettings.add("ReadBoardReplyTimeout", &m_ui32ReadBoardReplyTimeout);
	m_oSettings.add("FlushBoardReplyTimeout", &m_ui32FlushBoardReplyTimeout);
	m_oSettings.add("DaisyModule", &m_bDaisyModule);

	m_oSettings.load();

	MissingSampleDelayBeforeReset = (uint32)rDriverContext.getConfigurationManager().expandAsUInteger(Token_MissingSampleDelayBeforeReset, 1000);
	DroppedSampleCountBeforeReset = (uint32)rDriverContext.getConfigurationManager().expandAsUInteger(Token_DroppedSampleCountBeforeReset, 5);
	DroppedSampleSafetyDelayBeforeReset = (uint32)rDriverContext.getConfigurationManager().expandAsUInteger(Token_DroppedSampleSafetyDelayBeforeReset, 1000);

	// default parameter loaded, update channel count and frequency
	this->updateDaisy(true);
}

void CDriverFreeEEG32::release(void)
{
	delete this;
}

const char* CDriverFreeEEG32::getName(void)
{
	return m_sDriverName.toASCIIString();
}

//___________________________________________________________________//
//                                                                   //

void CDriverFreeEEG32::updateDaisy(bool bQuietLogging)
{
	// change channel and sampling rate according to daisy module
	CConfigurationFreeEEG32::SDaisyInformation l_oDaisyInformation=CConfigurationFreeEEG32::getDaisyInformation(m_bDaisyModule?CConfigurationFreeEEG32::DaisyStatus_Active:CConfigurationFreeEEG32::DaisyStatus_Inactive);

	m_oHeader.setSamplingFrequency(l_oDaisyInformation.iSamplingRate);
	m_oHeader.setChannelCount(l_oDaisyInformation.iEEGChannelCount+l_oDaisyInformation.iAccChannelCount);

	if(!bQuietLogging)
	{
		m_rDriverContext.getLogManager() << LogLevel_Info << this->m_sDriverName << ": Status - " << CString(m_bDaisyModule?"Daisy":"** NO ** Daisy") << " module option enabled, " << m_oHeader.getChannelCount() << " channels -- " << (int)((m_bDaisyModule?2:1)*EEGValueCountPerSample) << " EEG and " << (int)AccValueCountPerSample << " accelerometer -- at " << m_oHeader.getSamplingFrequency() << "Hz.\n";
	}

	// microvolt for EEG channels
	for(int32 i=0; i<l_oDaisyInformation.iEEGChannelCount; i++)
	{
		m_oHeader.setChannelUnits(i, OVTK_UNIT_Volts, OVTK_FACTOR_Micro);
	}

	// undefined for accelerometer/extra channels
	for(int32 i=0; i<l_oDaisyInformation.iAccChannelCount; i++)
	{
		m_oHeader.setChannelUnits(l_oDaisyInformation.iEEGChannelCount+i, OVTK_UNIT_Unspecified, OVTK_FACTOR_Base);
	}
}
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

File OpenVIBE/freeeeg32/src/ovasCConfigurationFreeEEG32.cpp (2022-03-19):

/*
 * FreeEEG32 driver for OpenViBE
 *
 * \author Jeremy Frey
 * \author Yann Renard
 *
 */
#include "ovasCConfigurationFreeEEG32.h"
#include <algorithm>
#include <string>

#if defined TARGET_OS_Windows
 #include <windows.h>
 #include <winbase.h>
 #include <cstdio>
 #include <cstdlib>
 #include <commctrl.h>
 #include <winsock2.h> // htons and co.
 //#define TERM_SPEED 57600
// #define TERM_SPEED CBR_115200 // FreeEEG32 is a bit faster than others
// #define TERM_SPEED 921600 // FreeEEG32 is a bit faster than others
 #define TERM_SPEED 1500000 // FreeEEG32 is a bit faster than others
#elif defined TARGET_OS_Linux
 #include <cstdio>
 #include <unistd.h>
 #include <fcntl.h>
 #include <termios.h>
 #include <sys/select.h>
 #include <netinet/in.h> // htons and co.
 #include <unistd.h>
// #define TERM_SPEED B115200
 #define TERM_SPEED 1500000
// #define TERM_SPEED 921600
#else
#endif

#define boolean OpenViBE::boolean
using namespace OpenViBE;
using namespace OpenViBE::Kernel;
using namespace OpenViBEAcquisitionServer;

#define MAXIMUM_SERIAL_TTY     (32)
#define MAXIMUM_SERIAL_USB_TTY (128-MAXIMUM_SERIAL_TTY)
#define MAXIMUM_SERIAL_ACM_TTY (256-MAXIMUM_SERIAL_USB_TTY)

uint32 OpenViBEAcquisitionServer::CConfigurationFreeEEG32::getMaximumTTYCount(void)
{
	return MAXIMUM_SERIAL_ACM_TTY + MAXIMUM_SERIAL_USB_TTY + MAXIMUM_SERIAL_TTY;
}

CString OpenViBEAcquisitionServer::CConfigurationFreeEEG32::getTTYFileName(const uint32 ui32TTYNumber)
{
	char l_sBuffer[1024];
#if defined TARGET_OS_Windows
	::sprintf(l_sBuffer, "\\\\.\\COM%u", ui32TTYNumber);
#elif defined TARGET_OS_Linux
	if(ui32TTYNumber<MAXIMUM_SERIAL_USB_TTY)
	{
		::sprintf(l_sBuffer, "/dev/ttyUSB%u", ui32TTYNumber);
	}
	else if(ui32TTYNumber<MAXIMUM_SERIAL_ACM_TTY)
	{
		::sprintf(l_sBuffer, "/dev/ttyACM%u", ui32TTYNumber-MAXIMUM_SERIAL_USB_TTY);
	}
	else
	{
		::sprintf(l_sBuffer, "/dev/ttyS%u", ui32TTYNumber-MAXIMUM_SERIAL_ACM_TTY);
	}
#else
	::sprintf(l_sBuffer, "");
#endif
	return l_sBuffer;
}

bool OpenViBEAcquisitionServer::CConfigurationFreeEEG32::isTTYFile(const CString& sFileName)
{
#if defined TARGET_OS_Windows
	HANDLE l_pFile=::CreateFile(
		(LPCSTR)sFileName,
		GENERIC_READ,
		0,
		0,
		OPEN_EXISTING,
		FILE_ATTRIBUTE_NORMAL,
		0);
	if(l_pFile == INVALID_HANDLE_VALUE || l_pFile == NULL)
	{
		return false;
	}
	CloseHandle(l_pFile);
	return true;
#elif defined TARGET_OS_Linux
	int l_iFile=::open(sFileName, O_RDONLY);
	if(l_iFile < 0)
	{
		return false;
	}
	close(l_iFile);
	return true;
#else
	// Caution, this path will claim all serial ports do exist because there was no platform specific implementation
	return true;
#endif
}
static void checkbutton_daisy_module_cb(::GtkToggleButton* pButton, CConfigurationFreeEEG32* pConfigurationFreeEEG32)
{
	pConfigurationFreeEEG32->checkbuttonDaisyModuleCB(gtk_toggle_button_get_active(pButton)?CConfigurationFreeEEG32::DaisyStatus_Active:CConfigurationFreeEEG32::DaisyStatus_Inactive);
}

CConfigurationFreeEEG32::CConfigurationFreeEEG32(const char* sGtkBuilderFileName, OpenViBE::uint32& rUSBIndex)
	:CConfigurationBuilder(sGtkBuilderFileName)
	,m_rUSBIndex(rUSBIndex)
{
	m_pListStore=gtk_list_store_new(1, G_TYPE_STRING);
}

CConfigurationFreeEEG32::~CConfigurationFreeEEG32(void)
{
	g_object_unref(m_pListStore);
}

boolean CConfigurationFreeEEG32::preConfigure(void)
{
	if(!CConfigurationBuilder::preConfigure())
	{
		return false;
	}
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

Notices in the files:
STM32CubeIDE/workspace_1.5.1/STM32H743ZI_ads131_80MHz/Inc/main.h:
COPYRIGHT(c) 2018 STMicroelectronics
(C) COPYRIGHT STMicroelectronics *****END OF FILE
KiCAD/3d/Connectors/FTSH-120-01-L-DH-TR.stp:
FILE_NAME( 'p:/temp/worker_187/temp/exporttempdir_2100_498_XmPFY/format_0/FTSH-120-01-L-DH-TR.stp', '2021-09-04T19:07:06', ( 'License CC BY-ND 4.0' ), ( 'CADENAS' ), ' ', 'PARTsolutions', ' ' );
